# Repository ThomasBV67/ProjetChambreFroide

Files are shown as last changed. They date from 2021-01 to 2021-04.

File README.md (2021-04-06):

# ProjetChambreFroide
## Résumé du projet
Ce répertoire github contient tous les fichiers en lien avec notre projet. Ce projet se résume en un système de mesures et mise en mémoire de températures. Un module principal affiche les températures mesurée, garde en mémoire cette information et permet d'avoir accès à un historique des températures enregistrées. Un nombre variable de modules de mesures envoie des trames LoRa, contenant les températures mesurées par les capteurs de températures connectés à ceux-ci, au module principal.

## Dossiers
#### Électrique
Contient tout les fichiers et dossiers en lien avec la partie électronique du projet.

#### getAdressesCapteurs
Contient le projet arduino de test unitaire pour obtenir l'adresse des capteurs de températures.

#### LoRaSender
Contient le projet arduino de test unitaire d'envoi de trames LoRa.

#### ProgrammeModulesCentraux
Contient le projet arduino utilisé dans les modules de capteurs.

#### ProgrammePontLoRa
Contient le projet arduino utilisé pour faire le pont entre les trames LoRa et la connection série avec l'ordinateur.

#### testCapteurs
Contient le projet arduino utilisé pour tester le concept du projet (obtient les températures et envoi) du côté arduino.

#### TestPi
Contient le projet Visual Studio utilisé pour tester les fonctionnalitées de Windows 10 IoT Core.

#### TestRecieve
Contient le projet arduino utilisé pour tester la réception de trames LoRa.

#### TestSender
Contient le projet arduino utilisé pour tester l'envoi de trames LoRa.

#### UI_ChambreFroide_V1
Contient le projet principal Visual Studio.

## Fichiers
#### System.Data.SQLite.dll
Librairie utilisée pour utiliser SQLite dans le programme principal.

#### firstDraftUI_Projet.png
Idée de base pour l'affichage des températures

## Installation
#### Programme des cartes
Avant de mettre le programme spécifique à une carte, le bootloader doit etre installé. [Comment installer un bootloader](https://support.arduino.cc/hc/en-us/articles/360012048100-How-to-burn-the-bootloader-in-an-Arduino-Nano-using-an-Arduino-UNO)
Avant d'installer le bootloader, assurez vous que les jumpers JP101 et JP102 sont ouverts. Assurez vous de les fermer après son installation.
##### Module pont
Le programme du module pont est disponible sous /ProgrammePontLoRa/ProgrammePontLoRa.ino
Le fichier doit etre ouvert avec le logiciel Arduino.
Le programme est fait pour fonctionner avec les cartes "Module" disponibles sous /Électrique/Module Central/Module Central.pro
Compilez et envoyez le programme à la carte avec le logiciel Arduino
S'assurer que les syncWord des modules LoRa des modules correspondent (Disponibles entre 0x00 et 0xFF)
```c++
LoRa.setSyncWord(0x45);
```
##### Modules centraux
Le programme des modules centraux est disponible sous /ProgrammeModulesCentraux/ProgrammeModulesCentraux.ino
Le fichier doit etre ouvert avec le logiciel Arduino.
Le programme est fait pour fonctionner avec les cartes "Module" disponibles sous /Électrique/Module Central/Module Central.pro
Les cartes doivent etres numérotés. Il faut modifier la constante "NUM_MODULE" en commençant par 1 et en augmentant de 1 pour chaque module prévu sur le réseau
S'assurer que les syncWord des modules LoRa des modules correspondent (Disponibles entre 0x00 et 0xFF)
```c++
LoRa.setSyncWord(0x45);
```
Compilez et envoyez le programme à la carte avec le logiciel Arduino

#### Programme Principal
L'ensemble du programme principal est disponible sous /UI_ChambreFroide_V1/UI_ChambreFroide_V1/
Le projet s'ouvre avec visual studio. S'assurer que l'extensions "Développement .net Desktop" est installée dans VS

## Utilisation
### Commandes
Les commandes sont tout d'abord envoyés à partir d'un ordinateur vers le module de transmission qui se charge d'envoyer les informations de série vers LoRa et vice-versa. La commande est ensuite envoyée en LoRa et est reçue par tous les modules. Les modules vérifient ensuite l'information pour savoir si elle leur est destinée. Elle sera destinée à un seul module. Le module concerné traite ensuite la commande et récupère les informations demandés auprès des capteurs. Il renvois ensuite en un ou plusieurs messages dépendamment de la nature de la commande originale. Les données de réponses sont envoyées en LoRa et récupérés par le module de transmission qui les convertit en série et les renvoie à l'ordinateur. 

#### getAddr 
Commande permettant de lire l'adresse de tous les capteurs branchés à un module spécifié. 
Exemple d'utilisation: 1getAddr 

Le numéro du module interrogé est tout d'abord inséré suivi de la commande. La commande retourne  

Les adresses des différents capteurs qui y sont connectés sont envoyés, espacés par '#'

#### getTemp 
Commande retournant la température du thermomètre désiré.  

Exemple: 1getTemp-1 

Tout comme la première commande, le numéro de module est spécifié au départ. Le dernier chiffre correspond au numéro du thermomètre à lire. Le numéro correspond à la position d'arrivée de l'adresse dans la commande précédente.  

Le module interrogé renvoie une trame ressemblant à T#ADDR
Où T correspond à la température du capteur et ADDR à son addresse. L'addresse agit comme un checksum pour le programme principal.

### Principe de fonctionnement du programme principal
La prise de temprature par le programme principal fonctionne selon un principe d'action-réaction. Une premiere lecture est déclenchée par un timer, cette lecture est définie par l'envoi d'une commande "getTemp" et l'attente de sa réponse.
À partir de ce moment, deux actions sont possibles, soit la réponse du capteur est reçue, elle est donc validée et traitée. Soit un timer de timeout se déclenche, ce timer sert à protéger le programme contre les trames perdues. Lors de son déclenchement, le programme tentera de recontacter le capteur. Apres 4 essais échoués de suite, le programme abandonne, il marque donc le capteur comme déffectueux (La température est remplacé par "ERR" sur fond mauve.) et passe au prochain capteur.

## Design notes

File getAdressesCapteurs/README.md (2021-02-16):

# getAdressesCapteurs
Ce programme permet à un arduino, connecté à un ou des capteurs de température DS18B20, d'afficher l'adresse de chaque capteur connecté à celui-ci sur le port série.

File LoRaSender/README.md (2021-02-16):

# LoRaSender
Ce programme permet à un arduino, connecté à un module LoRa, d'envoyer les valeurs de tous les capteurs connectés à celui-ci via un lien LoRa.

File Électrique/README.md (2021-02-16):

# Électrique
## Dossiers
#### Module Central
Ce dossier contient le projet KiCad du PCB des modules de mesure de température.

## Fichiers
#### COM-13909.lib / COM-13909.step / MOD_COM-13909.kicad_mod
#### ProjetChambreFroide.bck / ProjetChambreFroide.dcm / ProjetChambreFroide.lib
Fichiers de librairies contenant entre autre l'emprunte du modem LoRa.

#### Commande de pièces.txt
Contient la liste des pièces à commander pour le PCB.

#### Liste d'achat.xlsx
Liste de pièces à commander et prix pour le montage de 10 PCB.

#### Liste de pièces.txt
Liste de toutes les pièces nécessaire pour les PCB (à commander et déjà au magasin).

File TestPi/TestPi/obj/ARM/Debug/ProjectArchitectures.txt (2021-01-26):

C:\Users\Thomas\Desktop\Cegep\Final\ProjetChambreFroide\TestPi\TestPi\TestPi.csproj;arm

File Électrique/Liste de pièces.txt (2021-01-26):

1908-J49SML-F-G-G-K-16M0TR-ND	CRYSTAL 16MHZ 		0.40$ 		1
ATMEGA328P-AU-ND				MCU 8BIT			3.04$		1
931-1360-ND						Connecteur SMA		4.29$		1
1568-1394-ND					modem LoRa			8.77$		1
CP-037A-ND						Power Barrel		0.80$		1
2151-RST-W1B6-10808-22M-FY-001-ND	Antenne			6.84$		1
A113321-ND						Bornier à vis		1.66$		4
LM2937IMP-3.3TR-ND				Regulateur 3.3V		3.86$		1
151-1206-2-ND					Prise USB			0.77$		1
478-7800-1-ND					Diode Schhotky		0.51$		2
768-1007-2-ND					USB-UART			6.63$		1
DS18B20-ND						Thermomètre OneWire				1

C 	0.1		0805	7
C	10		0805	1
C	20p		0805	2
C	47p		0805	2
C	10n		0805	1

LED Rouge	0805	6

R 	330		0805	6
R 	1M		0805	1
R 	20		0805	2
R 	10 		0805	1
R	4.7K	0805	1

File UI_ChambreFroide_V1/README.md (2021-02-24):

# UI_ChambreFroide_V1
Projet Visual Studio contenant l'enregistrement des températures dans la database et l'interface graphique.

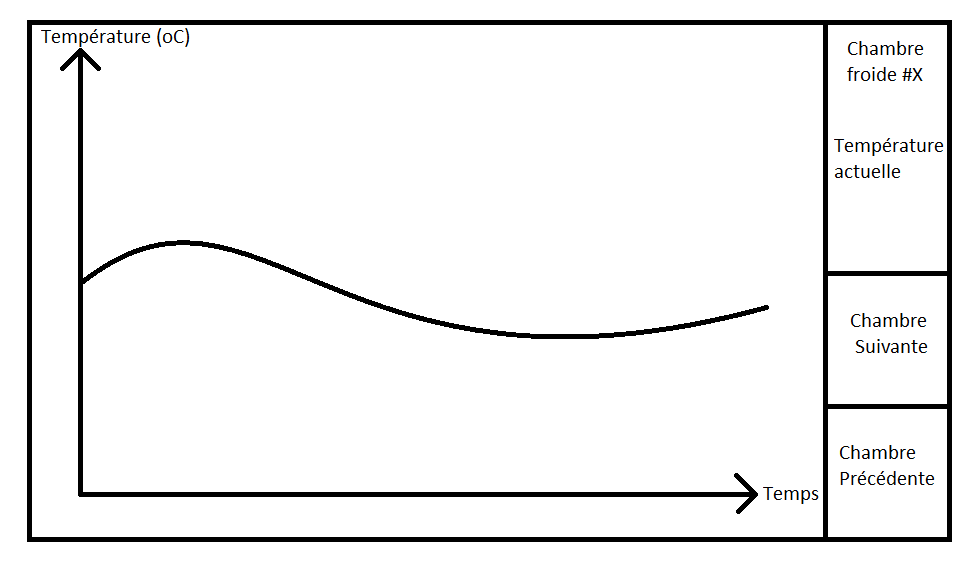
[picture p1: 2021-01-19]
firstDraftUI_Projet.png

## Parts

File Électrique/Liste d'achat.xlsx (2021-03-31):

Pièce | #Digikey | Prix | Place/carte | qté/1 carte | Prix/carte |  | À acheter
C 0,1 | 445-14435-2-ND | 0.37 | 8 | 8 | 2.96 |  | 40
C 10 | 445-11430-2-ND | 0.49 | 1 | 1 | 0.49 |  | 5
C 20p | 478-11887-2-ND | 0.33 | 2 | 2 | 0.66 |  | 10
LED | 475-1410-2-ND | 0.35 | 7 | 7 | 2.45 |  | 35
D Schottky | 478-7800-1-ND | 0.5 | 2 | 2 | 1 |  | 10
Jack connector | CP-002A-ND | 0.82 | 1 | 1 | 0.82 |  | 5
Bootloader conn | S2011E-03-ND | 0.64 | 1 | 1 | 0.64 |  | 5
SMA Connector | WM4088-ND | 5.09 | 1 | 1 | 5.09 |  | 5
USB | 151-1206-2-ND | 0.73 | 1 | 1 | 0.73 |  | 5
TERM BLK | 277-15492-ND | 2.16 | 4 | 4 | 8.64 |  | 20
R 330 | A129743TR-ND | 0.14 | 7 | 7 | 0.98 |  | 35
R 10K | RNCP0805FTD10K0TR-ND | 0.14 | 1 | 1 | 0.14 |  | 5
R 1M | P1MDATR-ND | 0.45 | 1 | 1 | 0.45 |  | 5
R 10 | 2019-RK73H2ATTD10R0FTR-ND | 0.14 | 1 | 1 | 0.14 |  | 5
R 4,7K | A130138TR-ND | 0.14 | 1 | 1 | 0.14 |  | 5
Reg 3v3 | LM2937IMP-3.3TR-ND | 3.79 | 1 | 1 | 3.79 |  | 5
Atmega328p | ATMEGA328P-AU-ND | 3.36 | 1 | 1 | 3.36 |  | 5
RFM95W | RFM95W-915S2-ND | 18.26 | 1 | 1 | 18.26 |  | 5
LVL-TRSL | 595-TXB0104RGYRG4 | 1.48 | 2 | 2 | 2.96 | Mouser.ca | 10
FT232 | 768-1007-2-ND | 6.65 | 1 | 1 | 6.65 |  | 5
DS18B20 | DS18B20+-ND | 7.62 | 1 | 1 | 7.62 |  | 5
Crystal | 1908-J49SML-F-G-G-K-16M0TR-ND | 0.39 | 1 | 1 | 0.39 |  | 5 | Total pour 1: |  | 81.35
 |  |  |  |  | 0 |  | 0 | Total pour | 5 | 406.75
PSU | B08DTRQG3T | 12.99 | 1 | 1 | 12.99 | Amazon.ca | 5

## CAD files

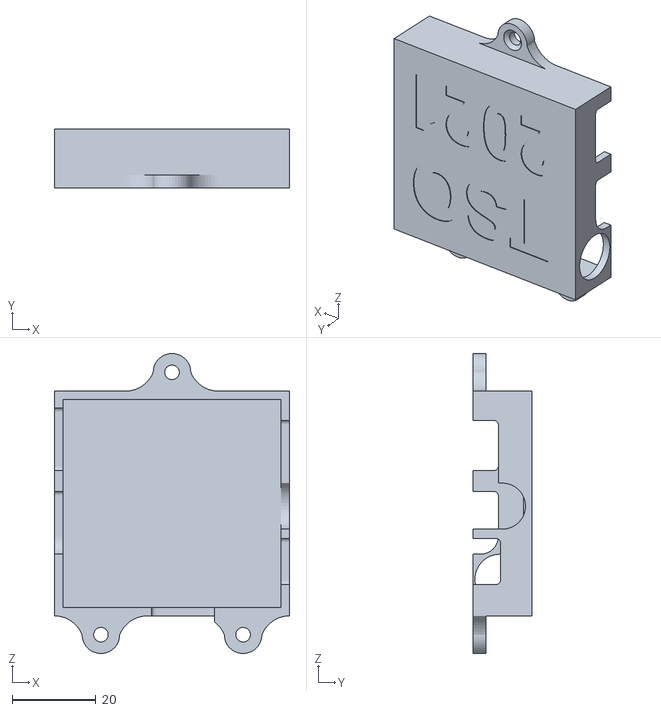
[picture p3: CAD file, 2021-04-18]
Objets 3d/Haut_module_central.stl
56.2 x 14.0 x 71.8

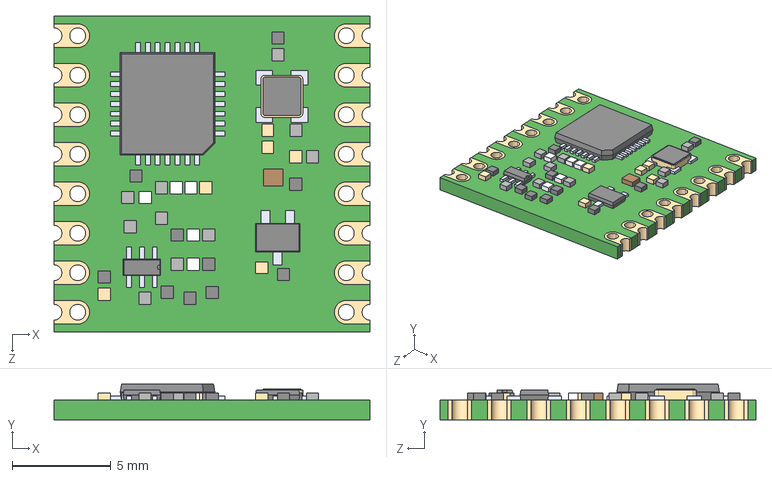
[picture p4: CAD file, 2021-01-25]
Électrique/COM-13909.step
16.0 x 1.80 x 16.0 mm

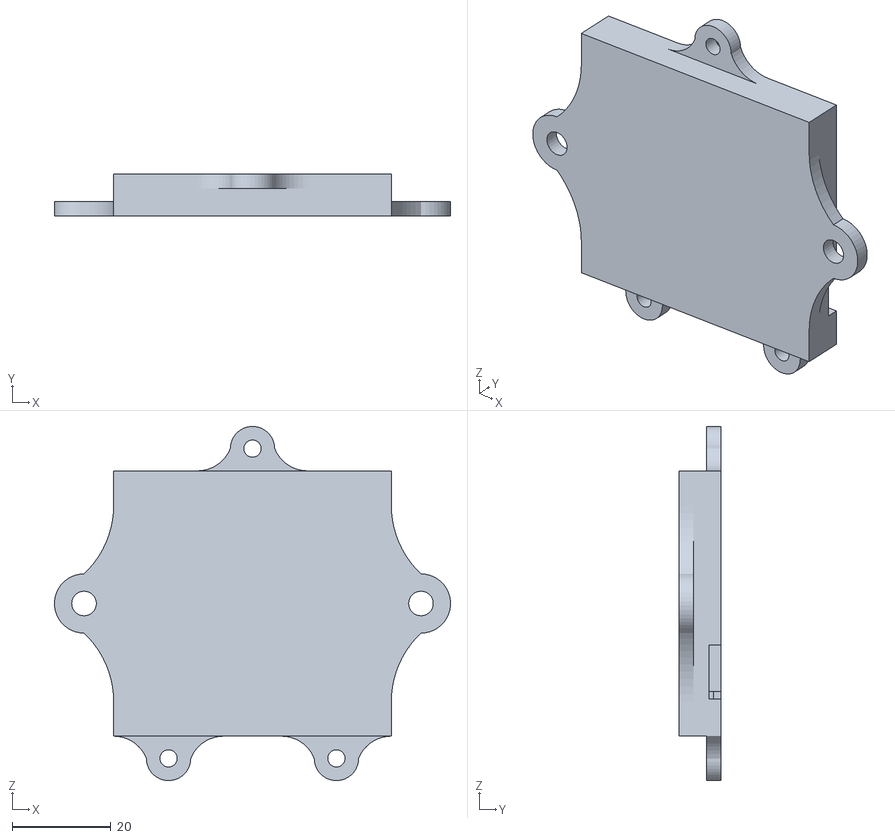
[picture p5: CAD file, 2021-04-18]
Objets 3d/Bas_module_central.stl
80.2 x 8.60 x 71.7

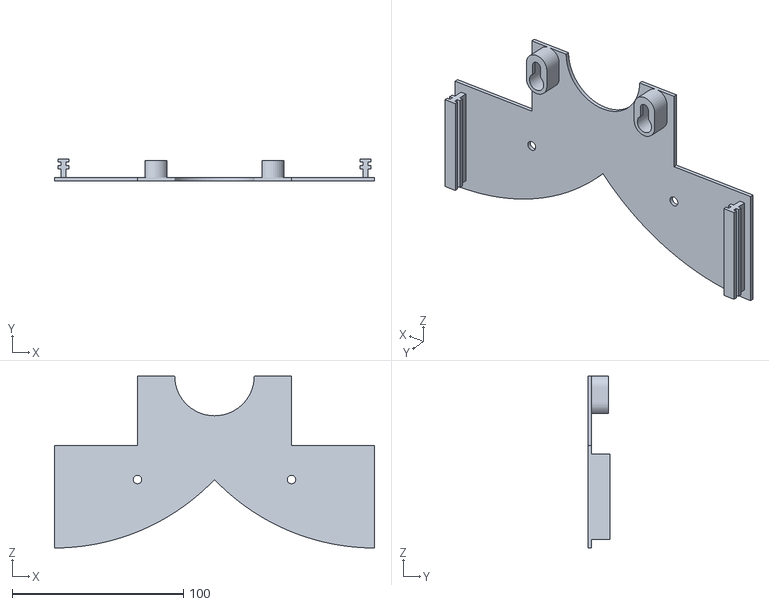
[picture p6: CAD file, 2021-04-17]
Objets 3d/Support écran.stl
187.0 x 12.8 x 100.5

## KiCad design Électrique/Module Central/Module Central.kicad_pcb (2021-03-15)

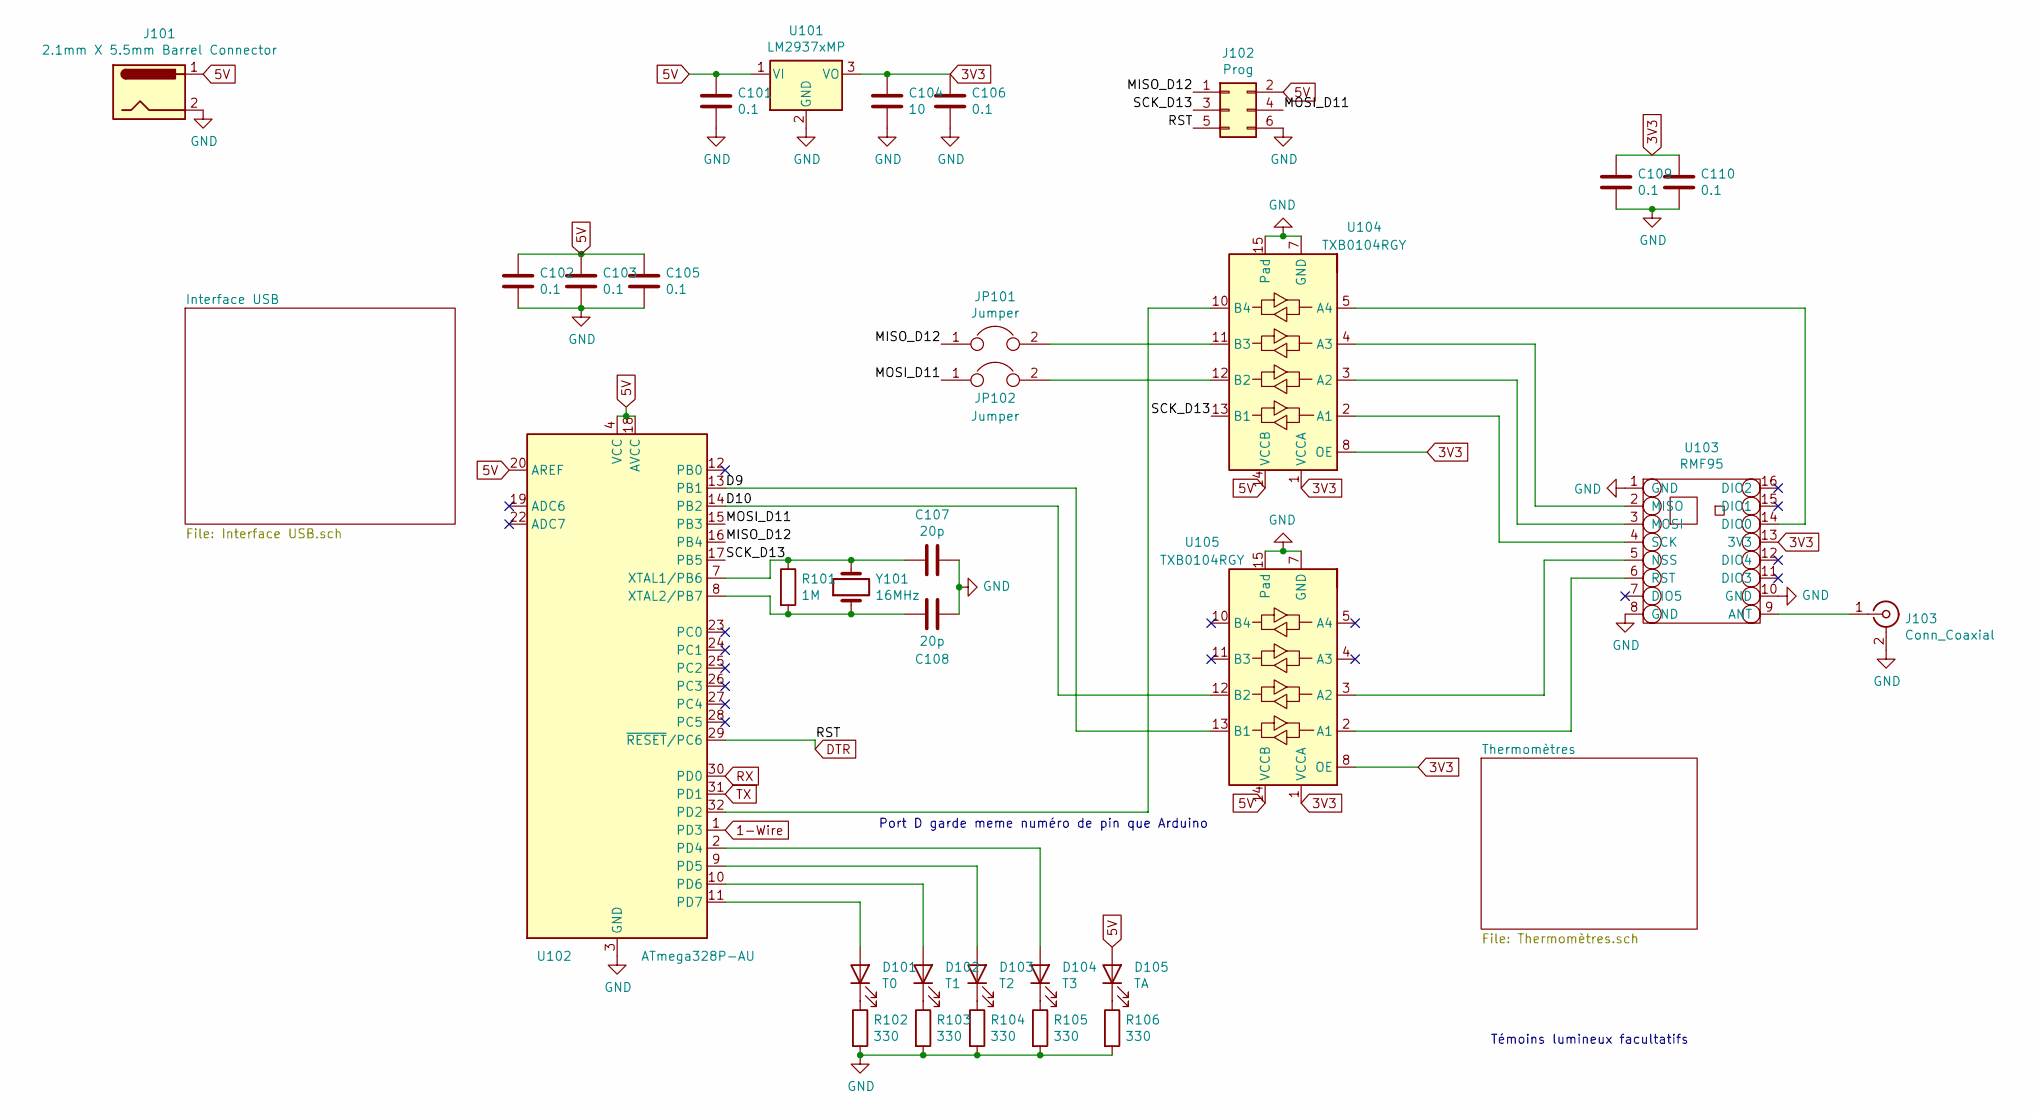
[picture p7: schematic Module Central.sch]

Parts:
C101, C102, C103, C105, C106, C109, C110: 0.1; C_0805_2012Metric
C104: 10; C_0805_2012Metric
C107, C108: 20p; C_0805_2012Metric
D101: T0; D_0805_2012Metric
D102: T1; D_0805_2012Metric
D103: T2; D_0805_2012Metric
D104: T3; D_0805_2012Metric
D105: TA; D_0805_2012Metric
J101: 2.1mm X 5.5mm Barrel Connector; BarrelJack_Horizontal
J102: Prog; PinSocket_2x03_P2.54mm_Vertical
J103: Conn_Coaxial; SMA_Molex_73251-2200_Horizontal
JP101, JP102: Jumper; SolderJumper-2_P1.3mm_Open_Pad1.0x1.5mm
R101: 1M; R_0805_2012Metric
R102, R103, R104, R105, R106: 330; R_0805_2012Metric
U101: LM2937xMP; SOT-223-3_TabPin2
U102: ATmega328P-AU; TQFP-32_7x7mm_P0.8mm
U103: RMF95; MOD_COM-13909
U104, U105: TXB0104RGY; Texas_S-PVQFN-N14
Y101: 16MHz; Crystal_SMD_HC49-SD

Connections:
1-Wire: U102.1 (PD3); also elsewhere on the board
3V3: C104.1, C106.1, C109.1, C110.1, U101.3 (VO), U103.13 (3V3), U104.1 (VCCA), U104.8 (OE), U105.1 (VCCA), U105.8 (OE); also elsewhere on the board
5V: C101.1, C102.1, C103.1, C105.1, D105.2 (A), J101.1, J102.2, U101.1 (VI), U102.4 (VCC), U102.6 (VCC), U102.18 (AVCC), U102.20 (AREF), U104.14 (VCCB), U105.14 (VCCB); also elsewhere on the board
/D9: U102.13 (PB1), U105.13 (B1)
/D10: U102.14 (PB2), U105.12 (B2)
/MISO_D12: J102.1, JP101.1, U102.16 (PB4)
/MOSI_D11: J102.4, JP102.1, U102.15 (PB3)
/SCK_D13: J102.3, U102.17 (PB5), U104.13 (B1)
DTR: J102.5, U102.29 (~RESET~/PC6); also elsewhere on the board
GND: C101.2, C102.2, C103.2, C104.2, C105.2, C106.2, C107.1, C108.1, C109.2, C110.2, J101.2, J102.6, J103.2 (Ext), R102.2, R103.2, R104.2, R105.2, R106.2, U101.2 (GND), U102.3 (GND), U102.5 (GND), U102.21 (GND), U103.1 (GND), U103.8 (GND), U103.10 (GND), U104.7 (GND), U104.15 (Pad), U105.7 (GND), U105.15 (Pad); also elsewhere on the board
unnamed: C107.2, R101.1, U102.7 (XTAL1/PB6), Y101.2
unnamed: C108.2, R101.2, U102.8 (XTAL2/PB7), Y101.1
unnamed: D101.1 (K), R102.1
unnamed: D101.2 (A), U102.11 (PD7)
unnamed: D102.1 (K), R103.1
unnamed: D102.2 (A), U102.10 (PD6)
unnamed: D103.1 (K), R104.1
unnamed: D103.2 (A), U102.9 (PD5)
unnamed: D104.1 (K), R105.1
unnamed: D104.2 (A), U102.2 (PD4)
unnamed: D105.1 (K), R106.1
unnamed: J103.1 (In), U103.9 (ANT)
unnamed: JP101.2, U104.11 (B3)
unnamed: JP102.2, U104.12 (B2)
unnamed: U102.32 (PD2), U104.10 (B4)
unnamed: U103.2 (MISO), U104.4 (A3)
unnamed: U103.3 (MOSI), U104.3 (A2)
unnamed: U103.4 (SCK), U104.2 (A1)
unnamed: U103.5 (NSS), U105.3 (A2)
unnamed: U103.6 (RST), U105.2 (A1)
unnamed: U103.14 (DIO0), U104.5 (A4)
RX: U102.30 (PD0); also elsewhere on the board
TX: U102.31 (PD1); also elsewhere on the board

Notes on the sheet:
Port D garde meme numéro de pin que Arduino
Témoins lumineux facultatifs

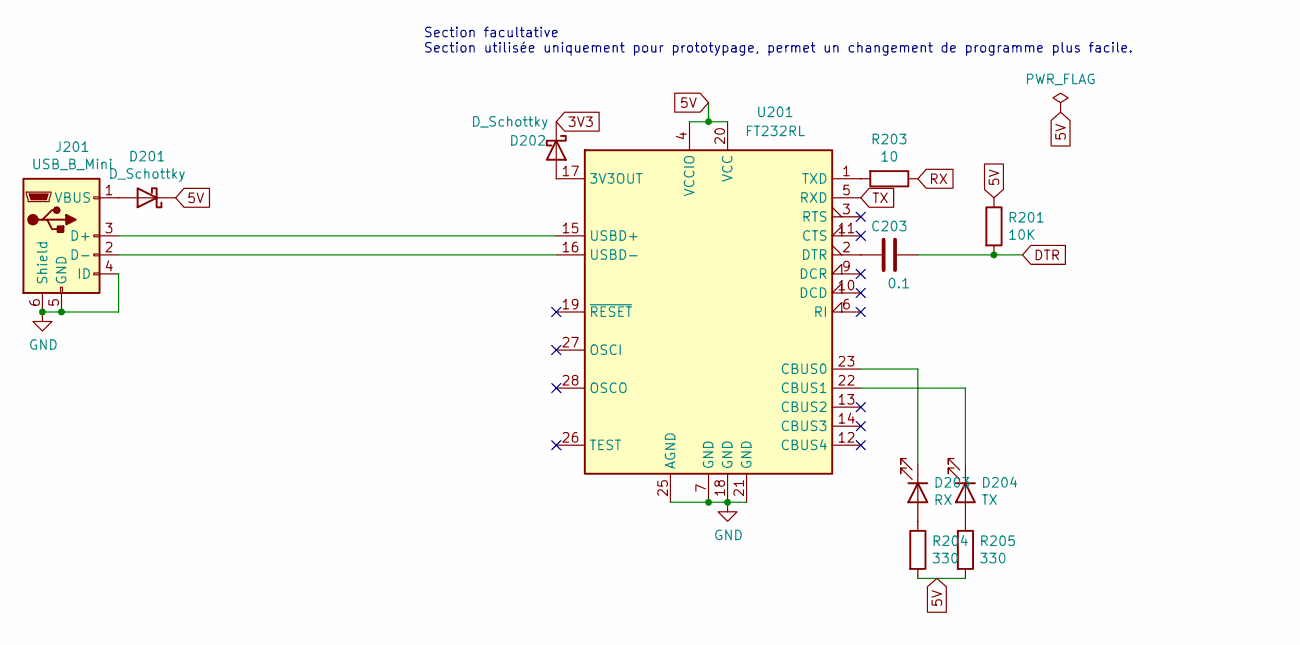
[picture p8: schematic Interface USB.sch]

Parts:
C203: 0.1; C_0805_2012Metric
D201, D202: D_Schottky; D_0805_2012Metric
D203: RX; D_0805_2012Metric
D204: TX; D_0805_2012Metric
J201: USB_B_Mini; USB_Mini-B_Lumberg_2486_01_Horizontal
R201: 10K; R_0805_2012Metric
R203: 10; R_0805_2012Metric
R204, R205: 330; R_0805_2012Metric
U201: FT232RL; SSOP-28_5.3x10.2mm_P0.65mm

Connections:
3V3: D202.1 (K); also elsewhere on the board
5V: D201.1 (K), R201.1, R204.2, R205.2, U201.4 (VCCIO), U201.20 (VCC); also elsewhere on the board
DTR: C203.1, R201.2; also elsewhere on the board
GND: J201.4 (ID), J201.5 (GND), J201.6 (Shield), U201.7 (GND), U201.18 (GND), U201.21 (GND), U201.25 (AGND); also elsewhere on the board
unnamed: C203.2, U201.2 (DTR)
unnamed: D201.2 (A), J201.1 (VBUS)
unnamed: D202.2 (A), U201.17 (3V3OUT)
unnamed: D203.1 (K), U201.23 (CBUS0)
unnamed: D203.2 (A), R204.1
unnamed: D204.1 (K), U201.22 (CBUS1)
unnamed: D204.2 (A), R205.1
unnamed: J201.2 (D-), U201.16 (USBD-)
unnamed: J201.3 (D+), U201.15 (USBD+)
unnamed: R203.2, U201.1 (TXD)
RX: R203.1; also elsewhere on the board
TX: U201.5 (RXD); also elsewhere on the board

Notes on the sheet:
Section facultative Section utilisée uniquement pour prototypage, permet un changement de programme plus facile.

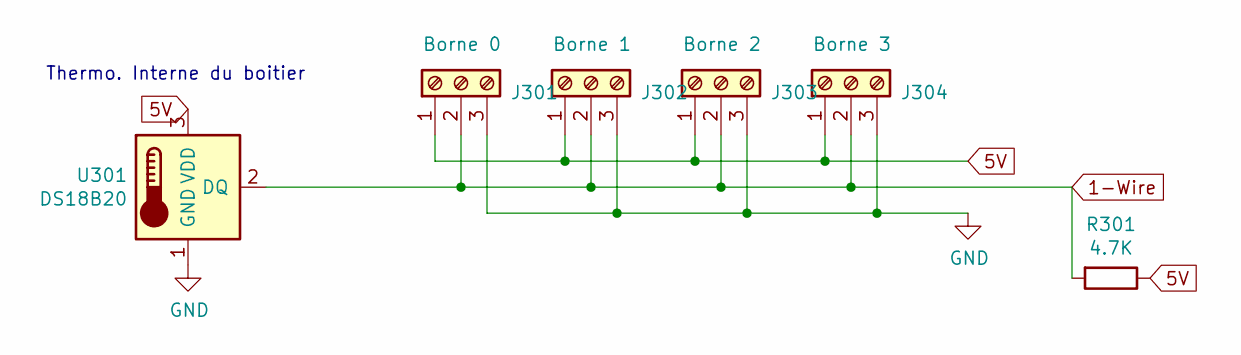
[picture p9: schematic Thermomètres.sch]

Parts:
J301: Borne 0; TerminalBlock_bornier-3_P5.08mm
J302: Borne 1; TerminalBlock_bornier-3_P5.08mm
J303: Borne 2; TerminalBlock_bornier-3_P5.08mm
J304: Borne 3; TerminalBlock_bornier-3_P5.08mm
R301: 4.7K; R_0805_2012Metric
U301: DS18B20; TO-92_Inline

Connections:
1-Wire: J301.2, J302.2, J303.2, J304.2, R301.2, U301.2 (DQ); also elsewhere on the board
5V: J301.1, J302.1, J303.1, J304.1, R301.1, U301.3 (VDD); also elsewhere on the board
GND: J301.3, J302.3, J303.3, J304.3, U301.1 (GND); also elsewhere on the board

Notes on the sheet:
Thermo. Interne du boitier

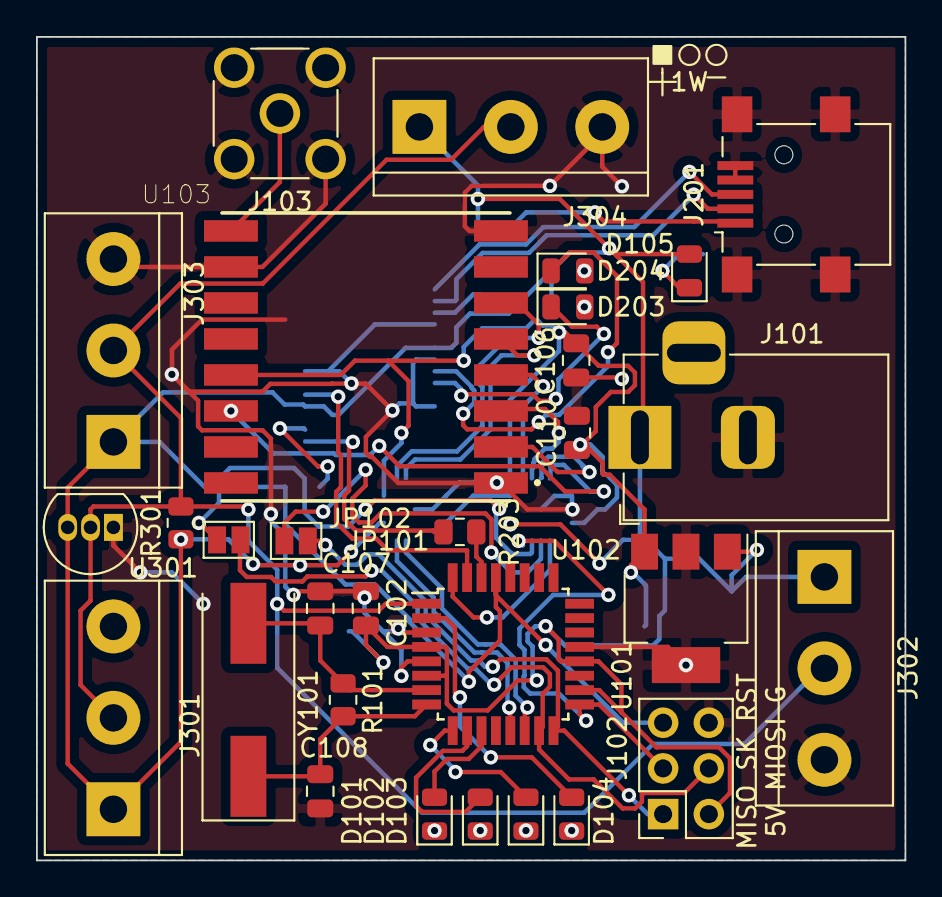
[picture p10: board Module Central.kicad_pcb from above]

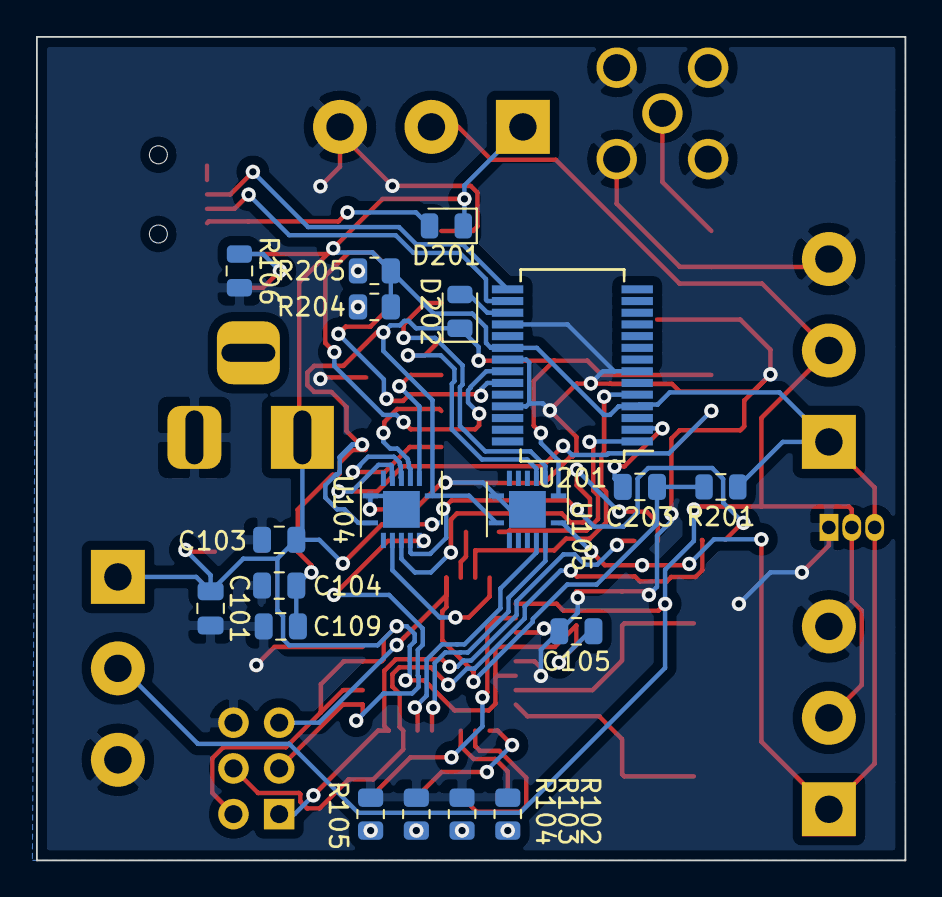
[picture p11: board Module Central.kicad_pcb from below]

Board: 2 copper layers, 48.2 x 45.8 mm, 49 parts (19 on the bottom side), 43 nets.

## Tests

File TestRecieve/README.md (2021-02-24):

# TestRevieve
Programme utilisé pour tester la partie réception de la librairie LoRa pour arduino. 

Arduino nano avec dragino LoRa + GPS kit

3 jumpers à l'opposé du module LoRa en pos 1-2

Brancher le nano comme si c'étais un uno sur un shield SANS OUBLIER LE 3.3V

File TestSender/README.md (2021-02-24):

# TestSender
Programme de test de module LoRa--Envoyeur
En premier lieu, le programme teste si le module LoRa est accesible et fonctionnel. Si il l'est, il commence l'envoi de messages numérotés.

Arduino nano avec dragino LoRa + GPS kit

3 jumpers à l'opposé du module LoRa en pos 1-2

Brancher le nano comme si c'étais un uno sur un shield SANS OUBLIER LE 3.3V

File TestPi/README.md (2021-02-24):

# TestPi
Ce dossier contient un programme utilisé pour tester le fonctionnement de Windows 10 IoT Core

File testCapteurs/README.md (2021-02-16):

# testCapteurs
Ce programme permet de tester l'aquisition de température des capteurs DS18B20 et d'envoyer ces informations par des trames personalisées sur le port série.

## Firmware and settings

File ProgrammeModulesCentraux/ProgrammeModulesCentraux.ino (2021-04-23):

#include <OneWire.h> 
#include <avr/wdt.h>

#include <DallasTemperature.h> 

#include <SPI.h>
#include <LoRa.h> 
String NUM_MODULE = "1";

//define the pins used by the transceiver module
#define ss 10
#define rst 9
#define dio0 2
// Data wire is plugged into port 2 on the Arduino 
#define ONE_WIRE_BUS 3

// Setup a oneWire instance to communicate with any OneWire devices 
OneWire oneWire(ONE_WIRE_BUS); 
// Pass our oneWire reference to Dallas Temperature. 
DallasTemperature sensors(&oneWire); 
// variable to hold device addresses 
DeviceAddress Thermometer; 

int deviceCount = 0; 
unsigned long previousMillis = 0;

void setup(void) 

{ 
  // start serial port 
  Serial.begin(115200); 
  Serial.println("Setup...");
  // Start up the library 
  sensors.begin(); 

    LoRa.setPins(ss, rst, dio0);
  
  //replace the LoRa.begin(---E-) argument with your location's frequency 
  //433E6 for Asia
  //866E6 for Europe
  //915E6 for North America
  while (!LoRa.begin(915E6)) {
    Serial.println(".");
    delay(500);
  }
  LoRa.setSyncWord(0x45);
  deviceCount = sensors.getDeviceCount(); 
  wdt_enable(WDTO_8S);
} 

void loop(void) {
  String addresse;
      // try to parse packet
  int packetSize = LoRa.parsePacket();
  if (packetSize) {
    // received a packet
    previousMillis = millis();
    // read packet
    while (LoRa.available()) {
      String LoRaData = LoRa.readString();
      //Serial.println(LoRaData);
      if(LoRaData == (NUM_MODULE + "getAddr\n")){
        //Serial.println("Requete d'addressage...");
        addresse = "";
        for (int i = 0;  i < deviceCount;  i++) 
        { 
          sensors.getAddress(Thermometer, i); 
          
          for(int j=0; j<=7; j++)
          {
            if (Thermometer[j] < 0x10) addresse += String(0);
            addresse += String(Thermometer[j], HEX); 
          }
          addresse += "#";
        }
        LoRa.beginPacket();
        LoRa.print(addresse);
        LoRa.endPacket();
        
      }else if(LoRaData.startsWith(NUM_MODULE + "getTemp-")){
        addresse = "";
        LoRaData.replace(NUM_MODULE + "getTemp-", "");
        LoRaData.trim();
        //Serial.println(LoRaData.toInt());
        sensors.requestTemperatures();

        addresse += (String)sensors.getTempCByIndex(LoRaData.toInt());
        addresse += "#";

        sensors.getAddress(Thermometer, LoRaData.toInt());
        for(int i=0; i<=7; i++)
          {
            if (Thermometer[i] < 0x10) addresse += String(0);
            addresse += String(Thermometer[i], HEX); 
          }
        
        LoRa.beginPacket();
        LoRa.print(addresse);
        LoRa.endPacket();
        
      }
    }
  }
  wdt_reset();
  if (millis()- previousMillis  >= 120000){
    while(1);
  }
  delay(50);
} 

  

void printAddress(DeviceAddress deviceAddress) 

{  

  for (uint8_t i = 0; i < 8; i++) 

  { 

    //Serial.print("0x"); 

    //if (deviceAddress[i] < 0x10) Serial.print("0"); 

    //Serial.print(deviceAddress[i], HEX); 

    //if (i < 7) Serial.print(", "); 

  } 

 // Serial.println(""); 

} 

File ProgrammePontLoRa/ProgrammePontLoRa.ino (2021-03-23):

#include <SPI.h>
#include <LoRa.h>
#include <avr/wdt.h>

//define the pins used by the transceiver module
#define ss 10
#define rst 9
#define dio0 2

int counter = 0;

void setup() {
  //initialize Serial Monitor
  Serial.begin(115200);
  while (!Serial);
  
  //setup LoRa transceiver module
  LoRa.setPins(ss, rst, dio0);
  
  //replace the LoRa.begin(---E-) argument with your location's frequency 
  //433E6 for Asia
  //866E6 for Europe
  //915E6 for North America
  while (!LoRa.begin(915E6)) {
    delay(500);
  }
   // Change sync word (0xF3) to match the receiver
  // The sync word assures you don't get LoRa messages from other LoRa transceivers
  // ranges from 0-0xFF
  LoRa.setSyncWord(0x45);
  wdt_enable(WDTO_8S);
}
void loop(){
  int packetSize = LoRa.parsePacket();
  if (packetSize) {
    while (LoRa.available()) {
      Serial.println(LoRa.readString());
    }
  }
  if(Serial.available()){
    LoRa.beginPacket();
    LoRa.print(Serial.readString());
    LoRa.endPacket();
  }
  wdt_reset();
}

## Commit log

2021-01-19 Ajout des fichiers déjà créés au repo
2021-01-19 Ajout du programme de test unitaire receveur LoRa
2021-01-25 Ajout et modification des programmes de test
2021-01-25 Ajout du schéma électrique
    [COM-13909.step, Interface USB.sch, Module Central.kicad_pcb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]
2021-01-25 Modification des programmes de test unitaires
2021-01-25 MAJ liste pieces
    [Module Central.kicad_pcb]
2021-01-26 Ajout d'un programme de test pour windows 10 iot core
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2021-01-26 Remise a zero du programme de l'interface graphique
2021-01-26 Ajout de librairies pour graphiques au programme de test du Pi
2021-01-27 Ajout de l'exemple de menu principal- Élian
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2021-02-01 Modification du format des fenêtres de l'interface
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2021-02-01 Ajout de la page de selection
2021-02-01 Page principale UI et Gerber générés
    [Module Central-B_Cu.gbr, Module Central-B_Paste.gbr, Module Central-B_SilkS.gbr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]
2021-02-01 Changement de fichier pour le code precedent
2021-02-02 Ajout de boutons pour changer de form
2021-02-02 Ajout DEL témoin
    [Module Central-B_Cu.gbr, Module Central-B_Mask.gbr, Module Central-B_SilkS.gbr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]
2021-02-02 Modification de l'ouverture de nouveaux forms
2021-02-02 Définition des tableaux qui contiennent les temps.
2021-02-02 Ajout début de database
2021-02-02 Début de fonction de la DB
2021-02-02 Ajout des programmes des microcontroleurs
2021-02-02 Version sommaire de la page de configuration
    [Liste d'achat.xlsx]
2021-02-03 Ajout de commentaires dans le programme d'UI
2021-02-03 Ajout de boutons retour pour chaque for
2021-02-05 Ajout de la configuration du port série
2021-02-08 Ajout de nugget et début de remaniment du transfer de données à la DB
2021-02-08 Progression de la connection a la db
2021-02-08 Début de decouverte de réseau
2021-02-08 Ajout des fonctions GetUnsetCapteurs et GetSetCapteurs
2021-02-08 Base de decouverte reseau
2021-02-08 Ajout de commentaires, deletion de code innutile
2021-02-08 Traitement de l'entrée série
2021-02-08 Ecriture dans la db fonctionelle
2021-02-09 Ajout de fonction pour ajouter et modifier des capteurs dans la database
2021-02-09 Choix de capteur pour l'historique
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2021-02-09 Ajout de la classe de température
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2021-02-10 Ajout de la fonction pour ajouter des temps a la db
2021-02-10 Essai d'implémentation de la sauvegarde des temps
2021-02-11 Correction de bugs de prise de température
2021-02-12 Correction de bugs variés et implémentation de protection contre les données de températures invalides
    [ProgrammeModulesCentraux.ino]
2021-02-13 Ajout de marqueurs de test pour vérifier la fiabilité du programme
2021-02-15 Retirer tous les fichiers qui ne servent pas et ajout de readme
2021-02-15 Retirer plus de fichiers innutiles
2021-02-16 Ajout de commentaires et modification des readme
2021-02-16 Finition des readme et ajout de commentaires
2021-02-17 Modification du mode de configuration
2021-02-22 Début de la fenêtre de modification de capteurs
2021-02-23 Progression de la modif de capteurs
2021-02-24 Correction des erreurs sur le schéma
    [Interface USB.sch, Module Central.sch]
2021-02-24 Modification PCB prete à faire
    [Interface USB.sch, Module Central.kicad_pcb, Module Central.sch]
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2021-02-24 PCB modifié
    [Module Central-B_Cu.gbr, Module Central-B_Mask.gbr, Module Central-B_SilkS.gbr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]
2021-03-09 Début de la création du clavier visuel
2021-03-09 Essai d'enregistrement dans la db
2021-03-09 Début de l'implémentation d'un affichage d'historique
2021-03-09 Ajout de code de test pour afficher des données de la db
2021-03-09 Modif de la requete sql
2021-03-10 Modification du layout de boutons de config et de temp actuelles
2021-03-10 Ajustement des tailles de colonnes de la config
2021-03-12 Ajout des controles pour changer de page
2021-03-15 Update du formatage de texte
2021-03-15 Update du formatage de texte 2
2021-03-15 Modification PCB
    Changement des Level shifters pour des pieces disponibles
    [Module Central.sch]
2021-03-15 Changement des info de debug de la page principale
2021-03-15 Changement des info de debug de la page principale 2
2021-03-15 Réduction du temps entre les prises de données
2021-03-15 Modif PCB en cours
    [Module Central.kicad_pcb, Module Central.sch]
2021-03-15 Bugfix de plantage quand erreur critique
2021-03-15 PCB Avec 2x 4Channel LevelShifters
    [Module Central-B_Cu.gbr, Module Central-B_Mask.gbr, Module Central-B_SilkS.gbr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]
2021-03-16 Meilleure gestion des erreurs
2021-03-16 Query filtrée par temps fonctionnelle et update de capteur par address
2021-03-16 Debut de sauvegarde de config
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2021-03-16 Ajout d'une fonction pour retirer des capteurs de la database
2021-03-16 Ajout d'un nugget package pour les graphiques
2021-03-16 Ajout de la fonction de suppression de capteur
2021-03-17 Plus de capteurs fictifs
2021-03-17 Bug dans le path des fichiers
2021-03-17 Ajout de bouton arret / depart et demarrage auto
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2021-03-23 Changement de l'acces à l'historique
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2021-03-29 MAJ de la liste d'achats pour la carte
    Liste d'achat complète des pièces du PCB
    [Liste d'achat.xlsx]
2021-03-31 MAJ liste matériel
    [Liste d'achat.xlsx]
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2021-03-31 Ajout de labels pour les erreurs du module 3
2021-04-06 Ajout de fonctionnalitées au graphique et cleanup de bugs
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2021-04-17 Ajout des modèles 3d des supports pour les cartes et l'écran
    [Bas_module_central.stl, Haut_module_central.stl, Support écran.stl]
2021-04-18 Ajustement des tolérances
    [Bas_module_central.stl, Haut_module_central.stl]
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
